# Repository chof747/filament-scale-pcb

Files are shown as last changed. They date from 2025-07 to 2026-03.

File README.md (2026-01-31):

# Samla Filamentalist Electronics

## Idea

This is the electronics part of the filamentalist samla box which consists of:

### 1. The scale breakout for each Filamentalist station that contains:

- A header to read from a load cell
- An HX711 ADC controller and circutry to read the load cell
- A peripheral connector to connect to the led and the button on the outside of the box of the filamentalist station
- An IDC header to connect to the central mcu unit

### 2. An MCU Breakout

A board that bears the MCU and brain of the Filamentalist Box it has

- IDC receiving headers for each scale
- A header to connect to an SHT40X breakout for environmental control
- A 0.9" OLED
- A reset and a mod button to controll the oled

## Components

- Arduino Nano as the MCU
- 0.9" OLED
- 2x SMD Push Buttons
- 3 IDC headers
- 1 JST XH 2.54mm header (environmental sensor)

- HX711 ADC
- Screw terminal for Load cell connections
- IDC Header to MCU
- Peripheral JST xh 2.54mm for peripherals

## Revision History

**V1.0** - Send to production 26.07.2025
**Breakout Board V1.1** - separated clock lines for the three scales

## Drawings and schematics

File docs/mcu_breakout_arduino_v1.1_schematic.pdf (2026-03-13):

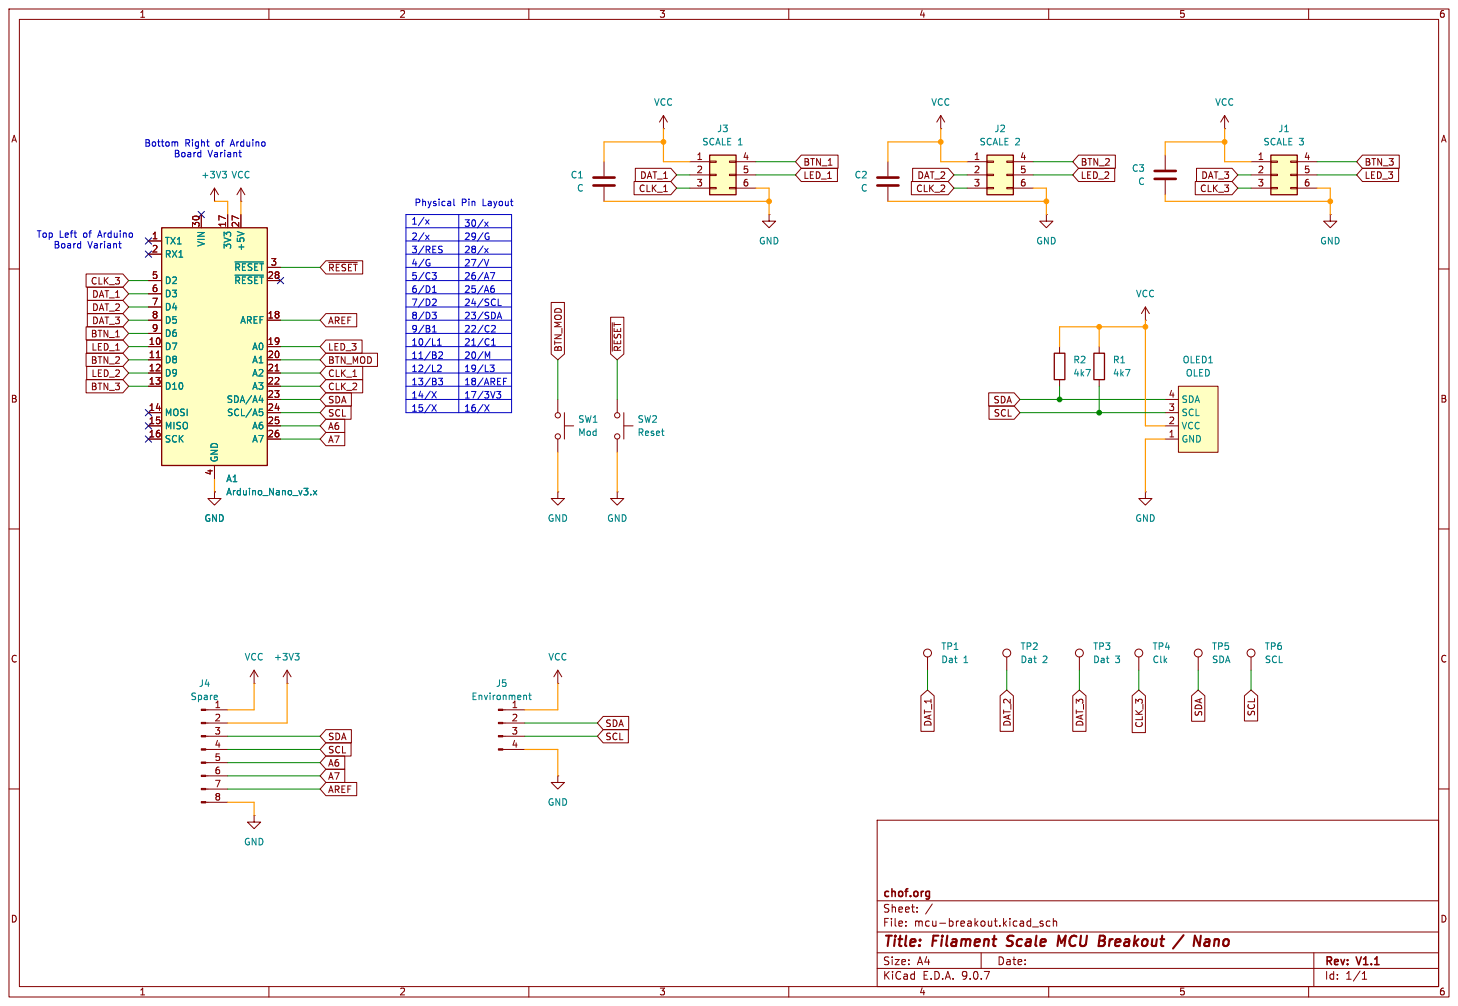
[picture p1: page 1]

File: mcu-breakout.kicad_sch Sheet: / chof.org

Id: 1/1 Title: Filament Scale MCU Breakout / Nano

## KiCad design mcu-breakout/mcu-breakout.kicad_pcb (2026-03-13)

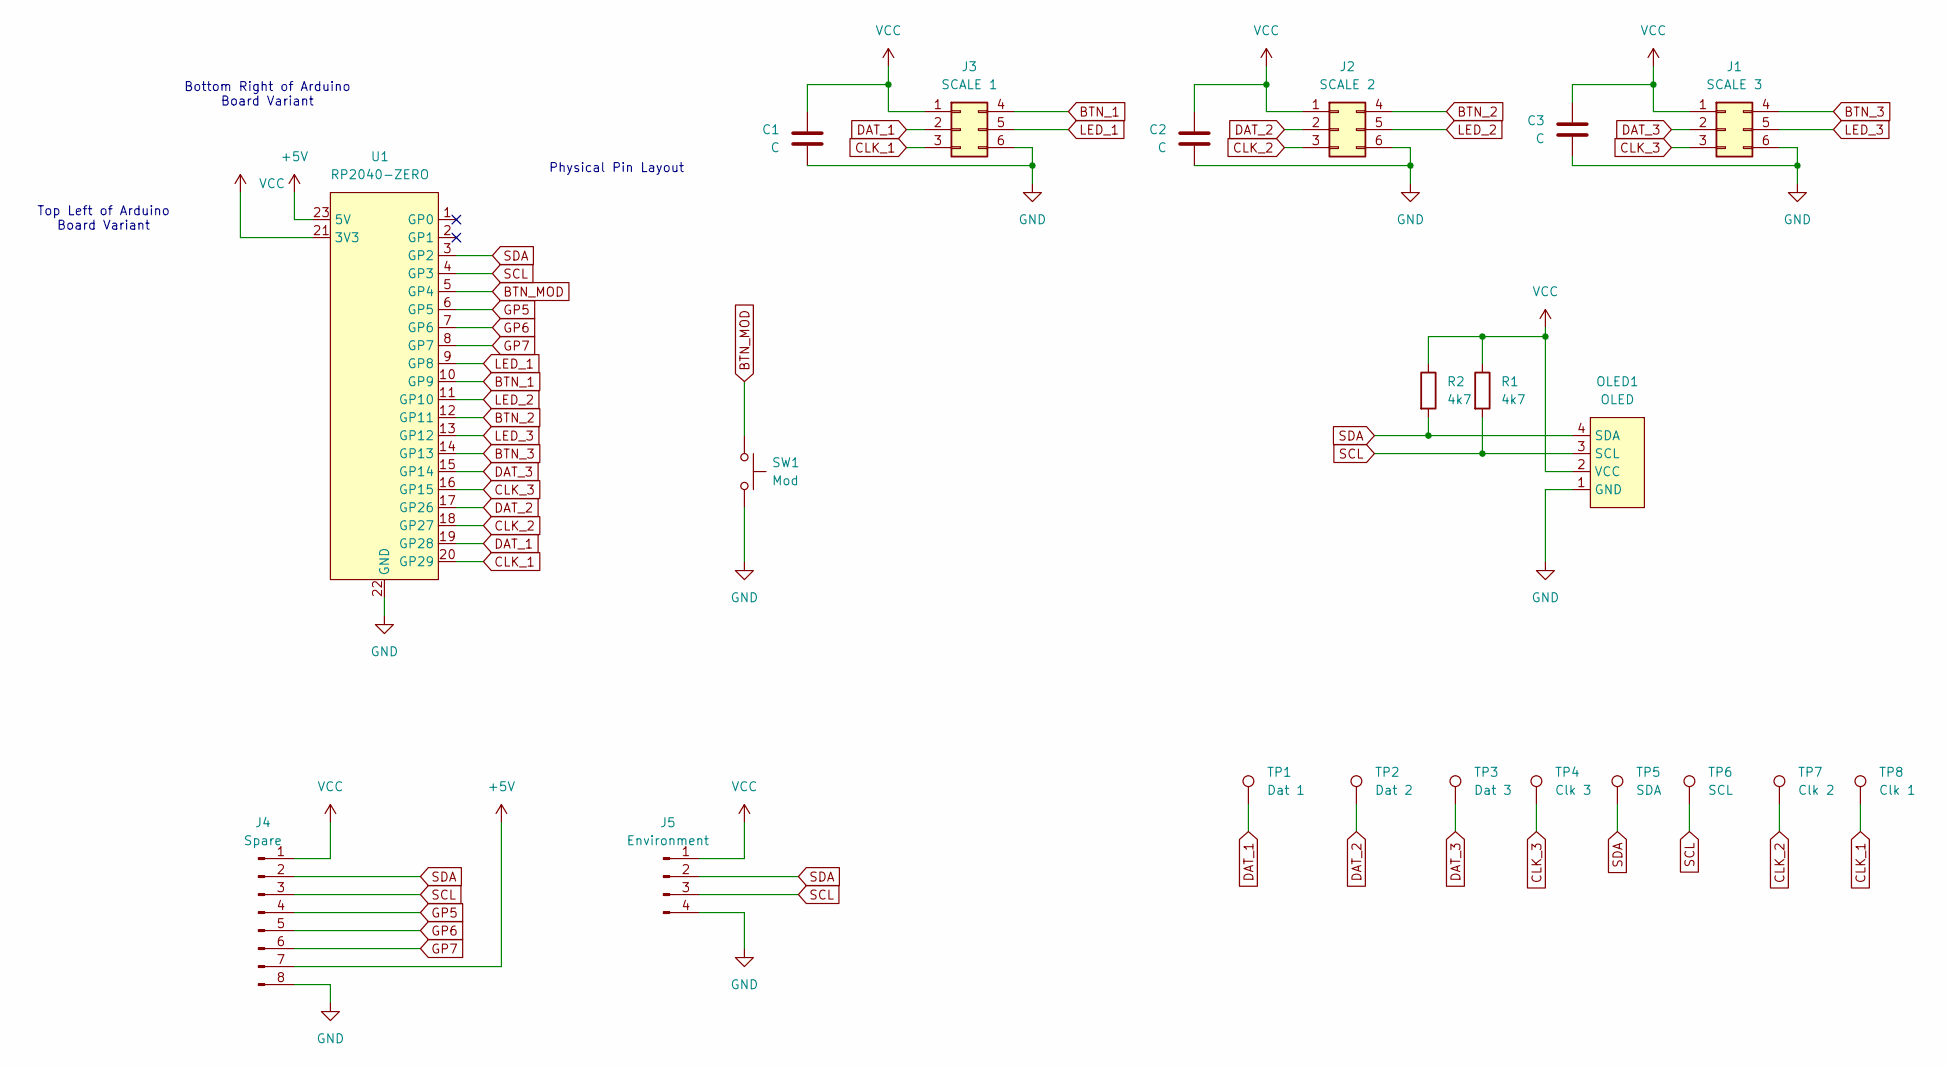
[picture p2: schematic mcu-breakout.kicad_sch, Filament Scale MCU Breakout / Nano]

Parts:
C1, C2, C3: C; C_0603_1608Metric_Pad1.08x0.95mm_HandSolder
J1: SCALE 3; HDR-TH_6P-P2.54-V-F-R2-C3-S2.54-4
J2: SCALE 2; HDR-TH_6P-P2.54-V-F-R2-C3-S2.54-4
J3: SCALE 1; HDR-TH_6P-P2.54-V-F-R2-C3-S2.54-4
J4: Spare; PinHeader_1x08_P2.54mm_Vertical
J5: Environment; JST_XH_B4B-XH-A_1x04_P2.54mm_Vertical
OLED1: OLED; OLED-TH_L38.0-W12.0_HS91L02W2C01; LCSC Part C5248081
R1, R2: 4k7; R_0603_1608Metric_Pad0.98x0.95mm_HandSolder
SW1: Mod; KEY-SMD_L3.9-W3.0-LS5.0-EH
TP1: Dat 1; TestPoint_Pad_D2.0mm
TP2: Dat 2; TestPoint_Pad_D2.0mm
TP3: Dat 3; TestPoint_Pad_D2.0mm
TP4: Clk 3; TestPoint_Pad_D2.0mm
TP5: SDA; TestPoint_Pad_D2.0mm
TP6: SCL; TestPoint_Pad_D2.0mm
TP7: Clk 2; TestPoint_Pad_D2.0mm
TP8: Clk 1; TestPoint_Pad_D2.0mm
U1: RP2040-ZERO; RP2040-ZERO-THP; LCSC Part C5350143

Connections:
+5V: J4.7, U1.23 (5V)
BTN_1: J3.4, U1.10 (GP9)
BTN_2: J2.4, U1.12 (GP11)
BTN_3: J1.4, U1.14 (GP13)
BTN_MOD: SW1.1, U1.5 (GP4)
CLK_1: J3.3, TP8.1, U1.20 (GP29)
CLK_2: J2.3, TP7.1, U1.18 (GP27)
CLK_3: J1.3, TP4.1, U1.16 (GP15)
DAT_1: J3.2, TP1.1, U1.19 (GP28)
DAT_2: J2.2, TP2.1, U1.17 (GP26)
DAT_3: J1.2, TP3.1, U1.15 (GP14)
GND: C1.2, C2.2, C3.2, J1.6, J2.6, J3.6, J4.8, J5.4, OLED1.1 (GND), SW1.2, U1.22 (GND)
GP5: J4.4, U1.6 (GP5)
GP6: J4.5, U1.7 (GP6)
GP7: J4.6, U1.8 (GP7)
LED_1: J3.5, U1.9 (GP8)
LED_2: J2.5, U1.11 (GP10)
LED_3: J1.5, U1.13 (GP12)
SCL: J4.3, J5.3, OLED1.3 (SCL), R1.2, TP6.1, U1.4 (GP3)
SDA: J4.2, J5.2, OLED1.4 (SDA), R2.2, TP5.1, U1.3 (GP2)
VCC: C1.1, C2.1, C3.1, J1.1, J2.1, J3.1, J4.1, J5.1, OLED1.2 (VCC), R1.1, R2.1, U1.21 (3V3)

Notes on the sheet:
Bottom Right of Arduino Board Variant
Top Left of Arduino Board Variant
Physical Pin Layout

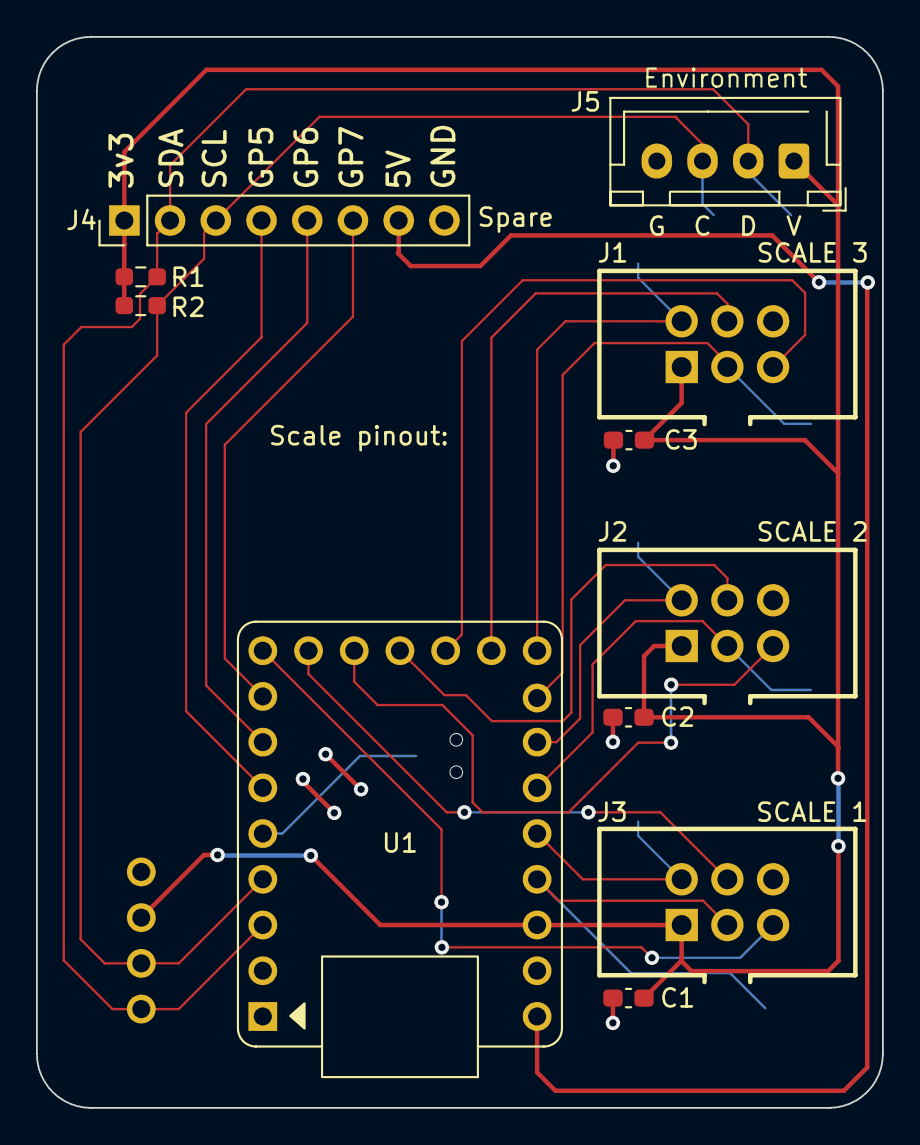
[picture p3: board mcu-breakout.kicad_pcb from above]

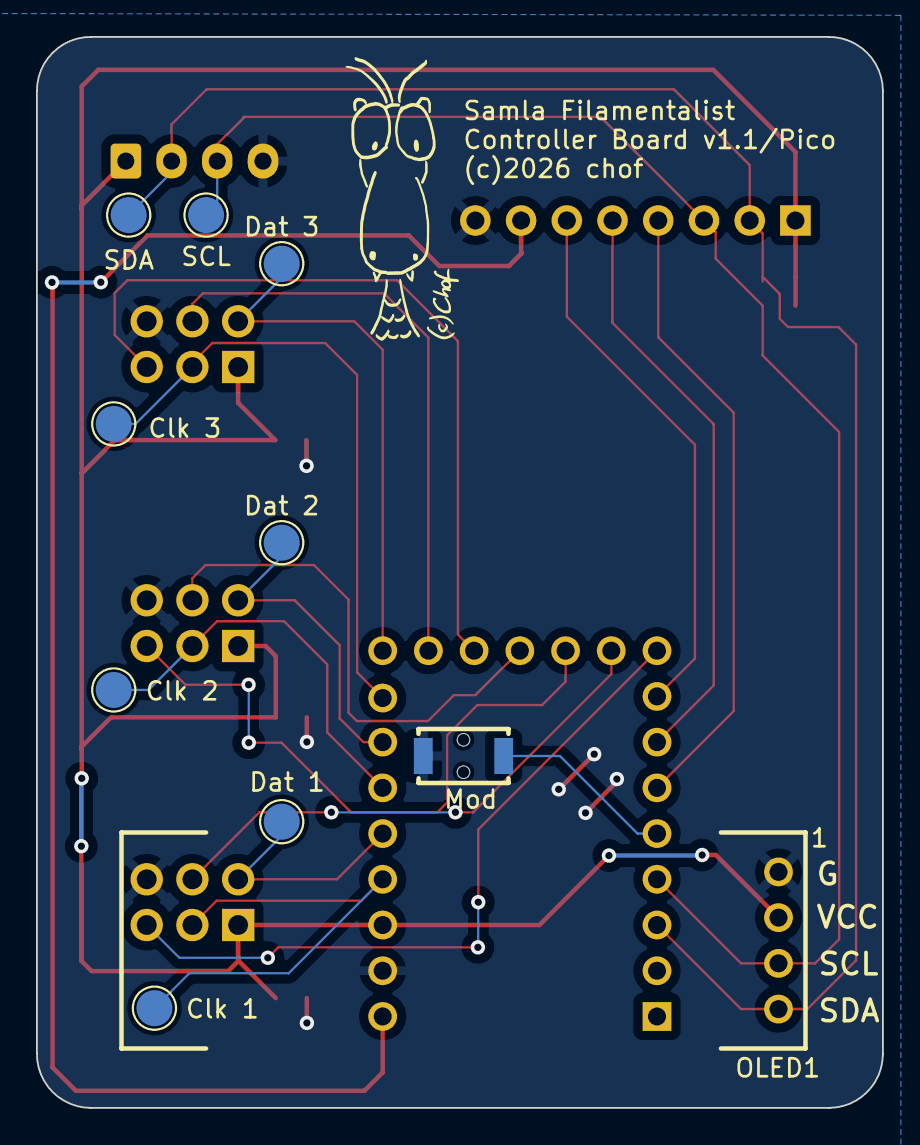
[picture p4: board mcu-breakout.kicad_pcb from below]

Board: 2 copper layers, 47.0 x 59.5 mm, 21 parts (10 on the bottom side), 21 nets.

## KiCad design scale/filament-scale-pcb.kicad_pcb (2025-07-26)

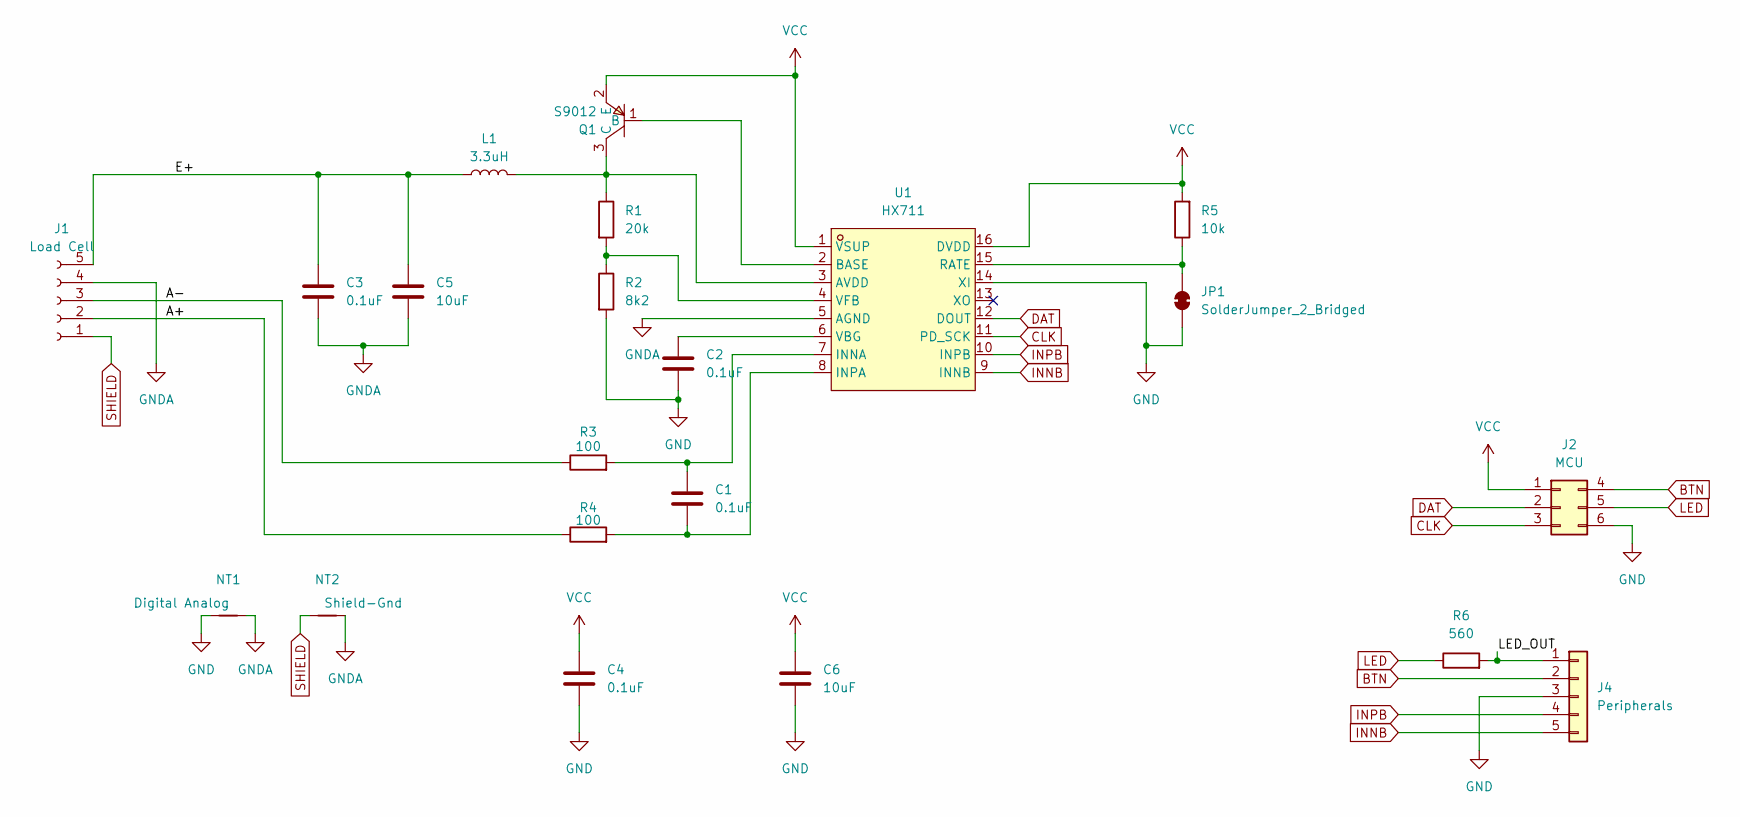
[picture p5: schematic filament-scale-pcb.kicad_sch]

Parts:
C1, C2, C3, C4: 0.1uF; C_0603_1608Metric_Pad1.08x0.95mm_HandSolder
C5, C6: 10uF; C_0603_1608Metric_Pad1.08x0.95mm_HandSolder
J1: Load Cell; CONN-TH_5P-P2.54_KF128-2.54-5P
J2: MCU; HDR-TH_6P-P2.54-V-F-R2-C3-S2.54-4
J4: Peripherals; JST_XH_B5B-XH-A_1x05_P2.54mm_Vertical
JP1: SolderJumper_2_Bridged; SolderJumper-2_P1.3mm_Bridged_RoundedPad1.0x1.5mm
L1: 3.3uH; L_0603_1608Metric_Pad1.05x0.95mm_HandSolder
NT1: Digital Analog; NetTie-2_SMD_Pad0.5mm
NT2: Shield-Gnd; NetTie-2_SMD_Pad0.5mm
Q1: S9012; SOT-23-3_L2.9-W1.3-P1.90-LS2.4-BR; LCSC Part C545570
R1: 20k; R_0603_1608Metric_Pad0.98x0.95mm_HandSolder
R2: 8k2; R_0603_1608Metric_Pad0.98x0.95mm_HandSolder
R3, R4: 100; R_0603_1608Metric_Pad0.98x0.95mm_HandSolder
R5: 10k; R_0603_1608Metric_Pad0.98x0.95mm_HandSolder
R6: 560; R_0603_1608Metric_Pad0.98x0.95mm_HandSolder
U1: HX711; SOP-16_L10.0-W3.9-P1.27-LS6.0-BL; LCSC Part C6705483

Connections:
/A+: J1.2, R4.1
/A-: J1.3, R3.1
/E+: C3.1, C5.1, J1.5, L1.1
/LED_OUT: J4.1, R6.2
BTN: J2.4, J4.2
CLK: J2.3, U1.11 (PD_SCK)
DAT: J2.2, U1.12 (DOUT)
GND: C2.1, C4.2, C6.2, J2.6, J4.3, JP1.1 (A), NT1.2, R2.2, U1.14 (XI)
GNDA: C3.2, C5.2, J1.4, NT1.1, NT2.1, U1.5 (AGND)
INNB: J4.5, U1.9 (INNB)
INPB: J4.4, U1.10 (INPB)
LED: J2.5, R6.1
unnamed: JP1.2 (B), R5.1, U1.15 (RATE)
unnamed: Q1.1 (B), U1.2 (BASE)
unnamed: L1.2, Q1.3 (C), R1.1, U1.3 (AVDD)
unnamed: C1.1, R3.2, U1.7 (INNA)
unnamed: C1.2, R4.2, U1.8 (INPA)
unnamed: C2.2, U1.6 (VBG)
unnamed: R1.2, R2.1, U1.4 (VFB)
SHIELD: J1.1, NT2.2
VCC: C4.1, C6.1, J2.1, Q1.2 (E), R5.2, U1.1 (VSUP), U1.16 (DVDD)

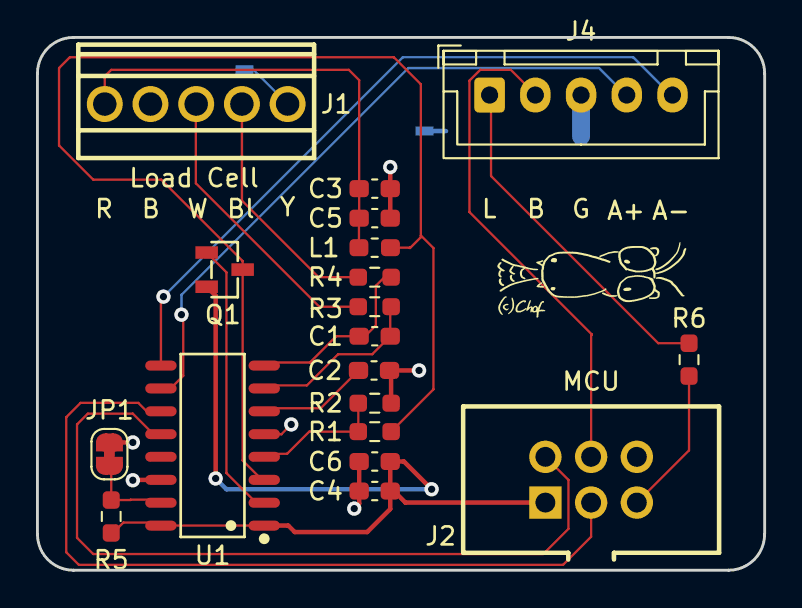
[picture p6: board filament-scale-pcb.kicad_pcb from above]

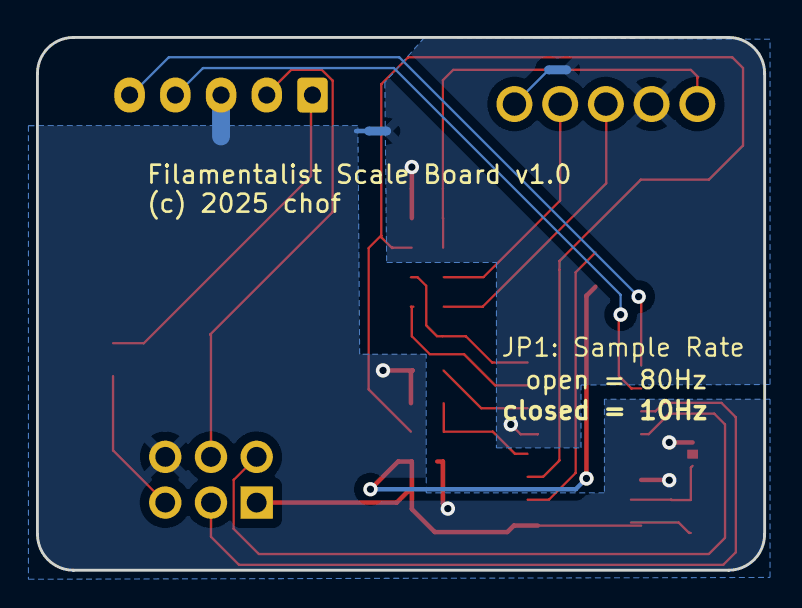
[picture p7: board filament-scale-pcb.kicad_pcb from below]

Board: 2 copper layers, 40.4 x 29.6 mm, 21 parts (2 on the bottom side), 21 nets.

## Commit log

2025-07-21 V1.0 of Filamentalist Samla electronics
    [filament-scale-pcb.kicad_pcb, filament-scale-pcb.kicad_sch, mcu-breakout.kicad_pcb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]
2025-07-26 initial version for production
    [filament-scale-pcb.kicad_pcb, filament-scale-pcb.kicad_sch, mcu-breakout.kicad_pcb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]
2026-01-31 Changed to separeted clock lines for the different scales
    [mcu-breakout.kicad_pcb, mcu-breakout.kicad_sch]
2026-03-13 changed to pico as a mcu
    [mcu-breakout.kicad_pcb, mcu-breakout.kicad_sch]
2026-03-13 added schema print out and table with physical pin numbering to arduino version
    [mcu-breakout.kicad_sch]
2026-03-13 V1.1 Pico version - last changes during upload
    [mcu-breakout.kicad_pcb]

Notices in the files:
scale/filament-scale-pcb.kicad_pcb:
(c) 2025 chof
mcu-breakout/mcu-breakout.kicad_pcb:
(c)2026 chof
